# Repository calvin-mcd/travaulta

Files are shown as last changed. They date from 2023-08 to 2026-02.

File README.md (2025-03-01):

# travaultas

The travaultas are a series of EC (topre) pcbs for mechvault's [Vault35](https://mechvault.net/products/vault-35-mini-keyboard) series designed by calvin0563. 

The series consists of the HHKB and WKL pcbs, both supporting a single bottomrow layout with the double 1.75u splitbars, and the Number/Macropad, supporting all layout options. 

Firmware source code and the OEM plate file are available in their respective folders. In order to fit the topre pcb into the case, small modifications to some housings are necessary. Please refer to the extensive build guide by cia\_moonchild in order to learn how to make the assembled pcb fit into the vault35 case.

[Build Guide!!!](https://imgur.com/a/L5vGjtF)

**BEWARE**: The HHKB pcb has been fully tested and confirmed to work. The WKL and Numpad have not yet been prototyped and still require firmware. 

## Layout

**HHKB**
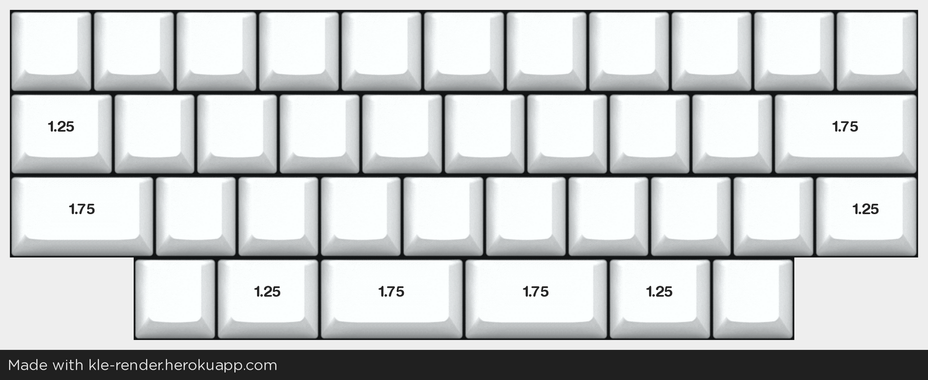
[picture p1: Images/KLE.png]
HHKB

[Link](http://www.keyboard-layout-editor.com/#/gists/d333b15956554a98cf3ed6f06e2de3bf)

**WKL**
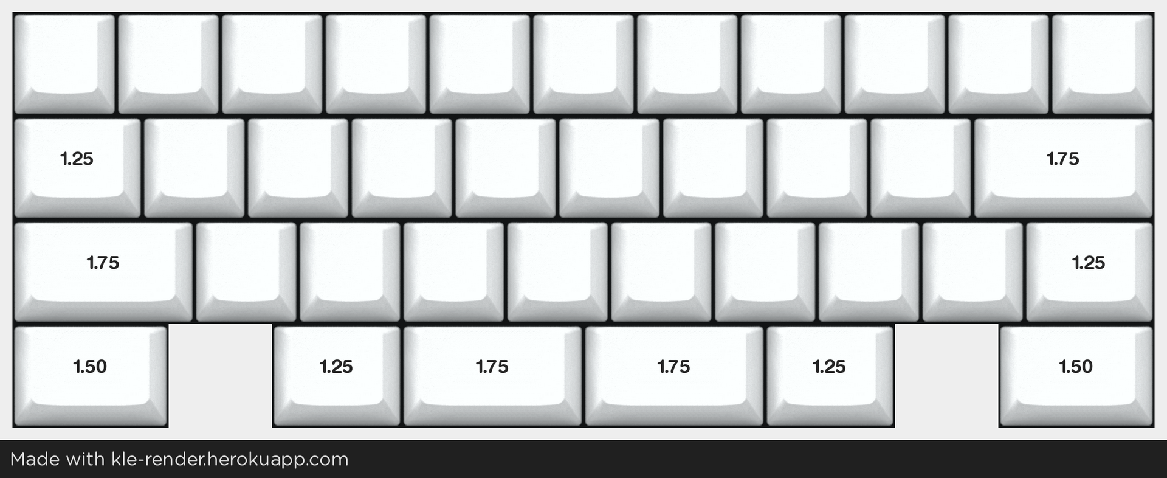
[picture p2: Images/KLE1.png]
WKL

[Link](https://www.keyboard-layout-editor.com/#/gists/da6e12de7bd5171aa8982730b8f45f17)

**NUMPAD**

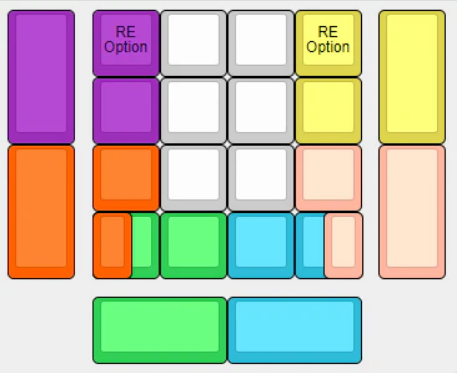
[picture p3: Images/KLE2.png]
Numpad


## Images
  
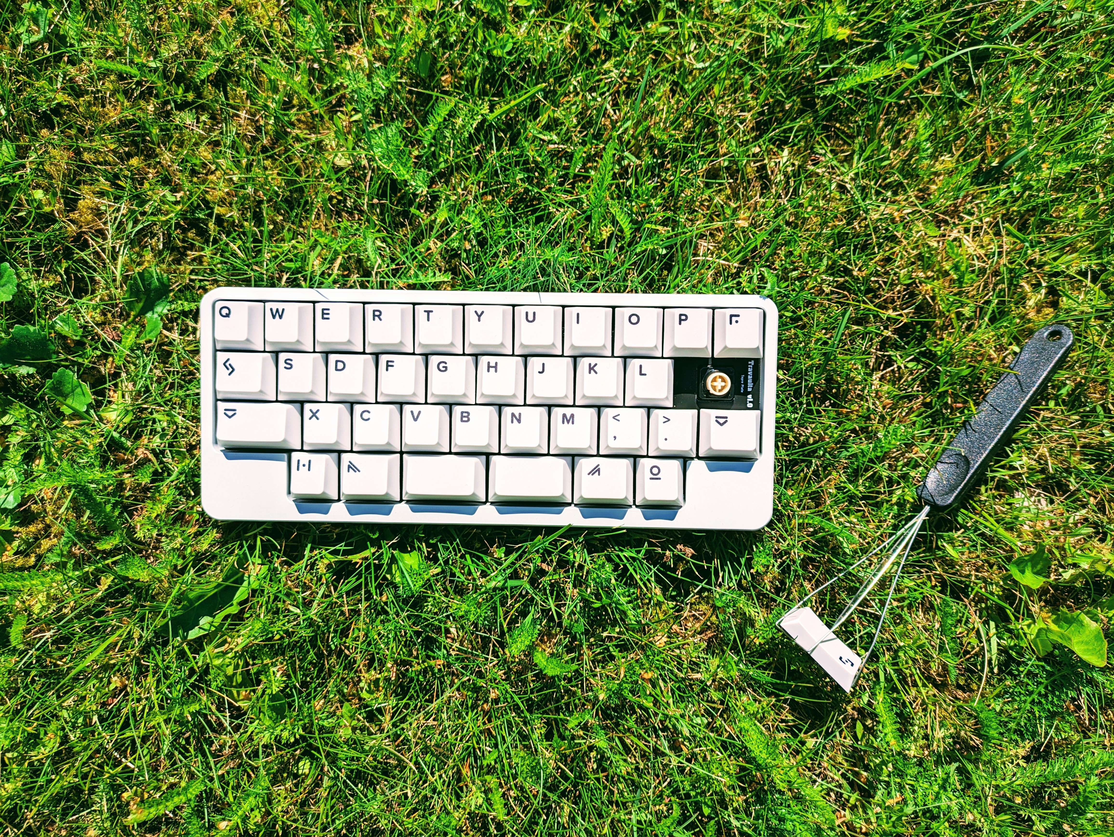
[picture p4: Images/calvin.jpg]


## Firmware

The basic EC firmware is ready to go and the source code is provided for tweaking any settings.

## Plates & Hardware

The plate file is OEM housing (so original, deskey, klc, pbb housings should all work). Be sure to order the plate in 1.2mm thickness regardless of material.

Furthermore, you will need 17x 10mm M2 screws and M2 nuts to assemble the HHKB and WKL pcbs. And 6x 10mm M2 screws and nuts to assemble numbpad.

## Disclaimer

1) Please proceed with caution with respect to copyright issues when using this repository
2) Take note that this is strictly for non-commercial use only
3) This PCB has been fully tested and confirmed to work. The members of the PCB development team are however not liable if you end up with a non-functional pcb. Order at your own risk. Support will not be provided but pull requests will be reviewed and possibly accepted.

## License

Shield: 

This work is licensed under a  
[Creative Commons Attribution-NonCommercial-ShareAlike 4.0 International License](http://creativecommons.org/licenses/by-nc-sa/4.0/).



## Credits

big thanks go out to Cain both for the inspiration and the support! My topre work is heavily lifted of Cipulot\#8455's open source work. I could not have done it without these resources. So I want to thank both cipulot and matthewdias\#2671 for their direct input, feedback and help along the way. Much much appreciated!

So many other thanks to go around, I fear I will forget people. There is Ciantha with their amazing guide! A whole bunch of early supporters that made the proto order possible. The keyboard Atelier discord for support. ssbb\#9052 with help with the firmware! And finally Alas/Sofia who decided to get a first GB for this on its feet!!

Any questions, contact Calvin0563 on Discord.

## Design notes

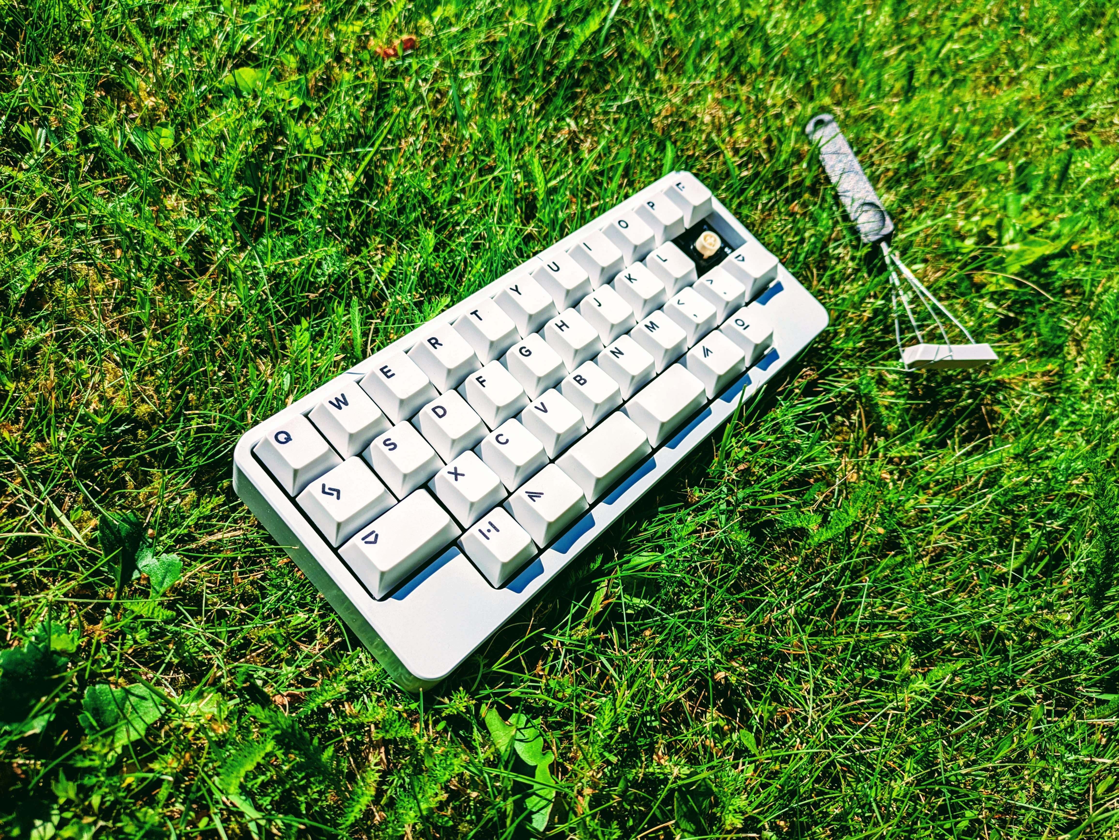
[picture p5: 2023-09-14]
Images/calvin (2).jpg

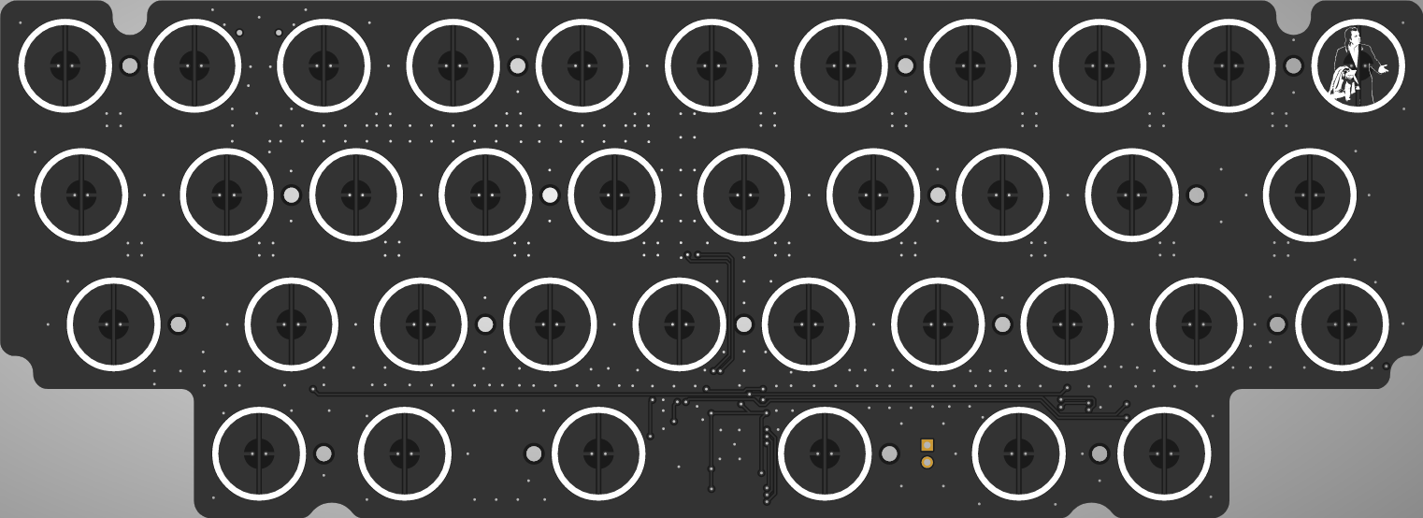
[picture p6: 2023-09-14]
Images/top.png

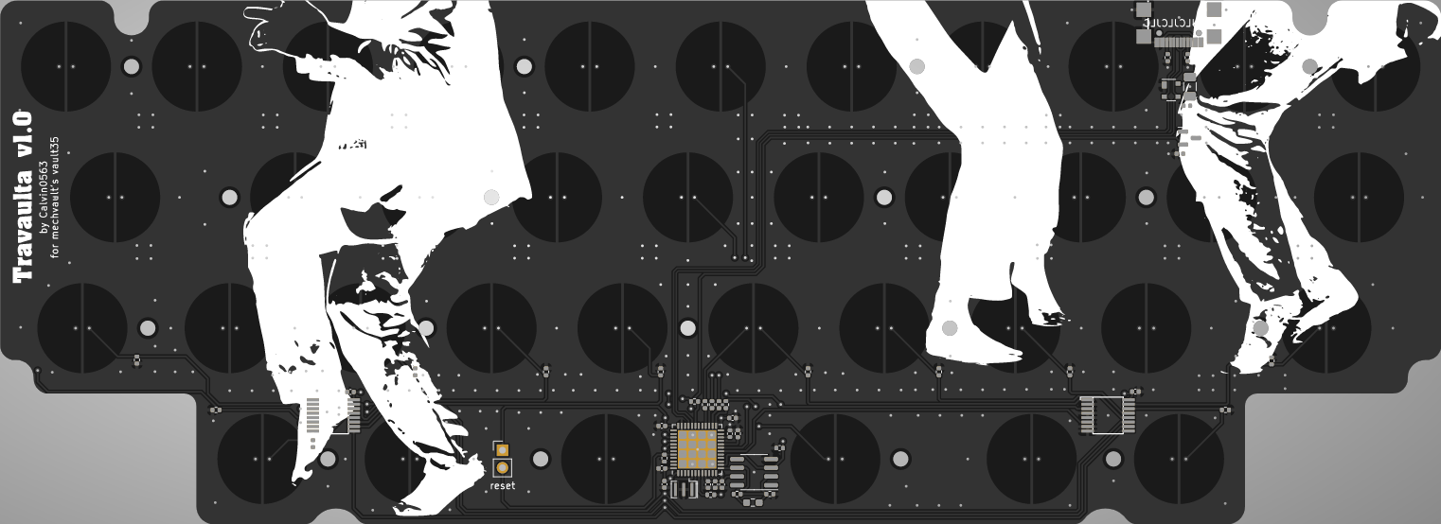
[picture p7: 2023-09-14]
Images/bottom.png

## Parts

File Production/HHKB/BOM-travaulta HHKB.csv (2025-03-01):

Comment | Designator | Footprint | LCSC | Quantity
1k | R23 | R_0402_1005Metric | C11702 | 1
STM32F401CBUx | U1 | QFN-48-1EP_7x7mm_P0.5mm_EP5.6x5.6mm | C118825 | 1
OPA350 | U5 | SOIC-8_3.9x4.9mm_P1.27mm | C13388 | 1
220p | C14 | C_0402_1005Metric | C1530 | 1
4.7u | C1 | C_0402_1005Metric | C23733 | 1
100 | R1,R2,R8,R9 | R_0402_1005Metric | C25076 | 4
100k | R10,R11,R12,R13,R14,R15,R16,R17,R19,R20,R21,R4,R5 | R_0402_1005Metric | C25741 | 13
10k | R3,R6,R7 | R_0402_1005Metric | C25744 | 3
5.1k | R18,R24 | R_0402_1005Metric | C25905 | 2
PRTR5V0U2X | D1 | SOT-143 | C2827688 | 1
TYPEC-304YSSW-ACP16 | USB1 | TYPEC-304YSSW-ACP16 | C2840392 | 1
100n | C10,C12,C13,C15,C6,C7,C8,C9 | C_0402_1005Metric | C307331 | 8
1u | C11,C4,C5 | C_0402_1005Metric | C52923 | 3
XC6206PxxxMR | U2 | SOT-23 | C5446 | 1
74HC4051 | U3,U4 | TSSOP16 | C5645 | 2
500mA | F_USBC1 | Fuse_1206_3216Metric | C70076 | 1
8 MHz | Y1 | Resonator_SMD_Murata_CSTxExxV-3Pin_3.0x1.1mm | C907975 | 1

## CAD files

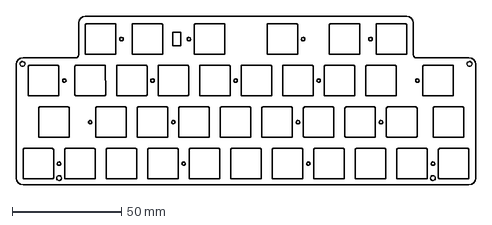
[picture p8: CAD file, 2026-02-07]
Production/HHKB/plate options/naevies.dxf
210.7 x 77.4 mm

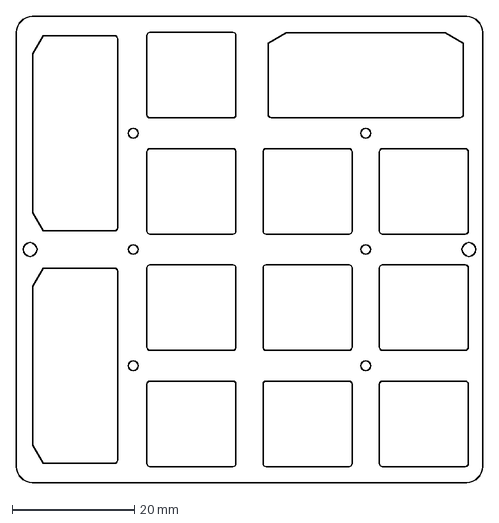
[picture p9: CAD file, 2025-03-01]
Production/Numpad/travaulta 16 2u.dxf
76.5 x 76.5 mm

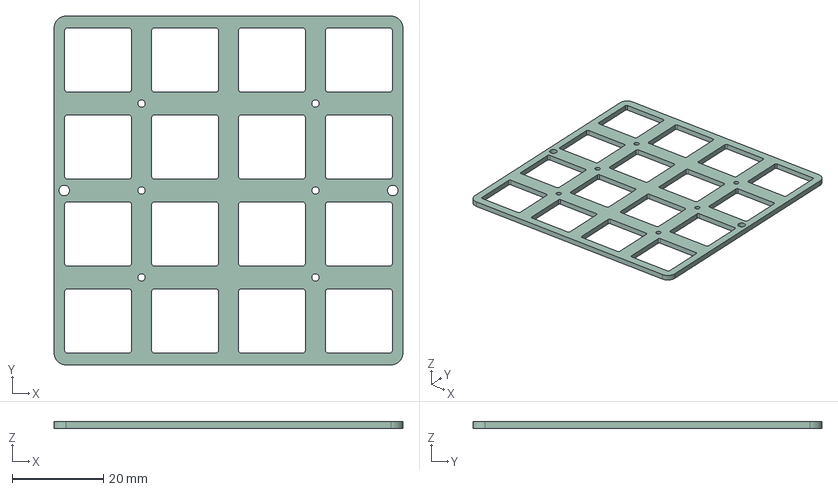
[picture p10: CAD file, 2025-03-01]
Project/travaulta 16/plate 1u threaded.step
76.5 x 76.4 x 1.60 mm

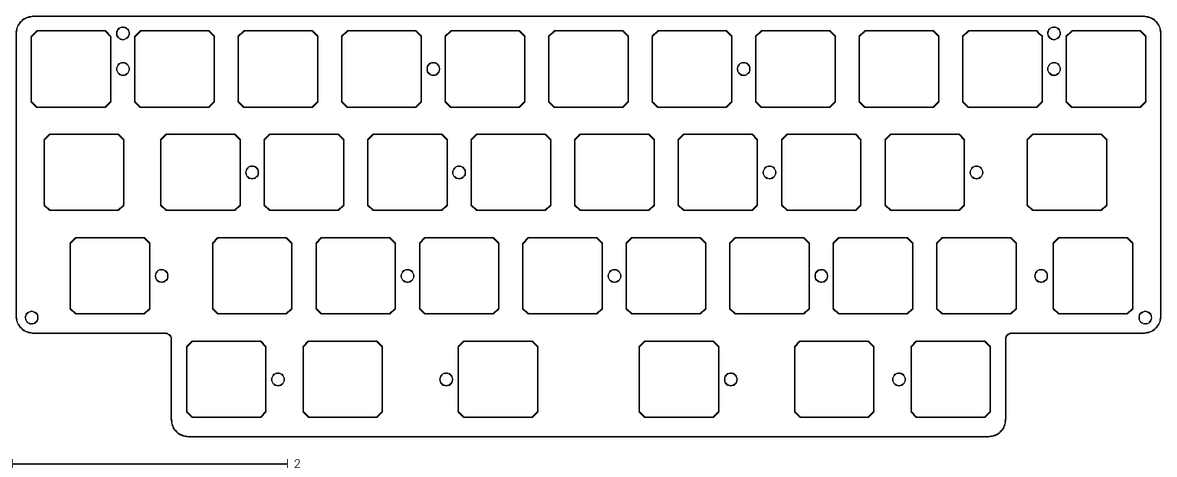
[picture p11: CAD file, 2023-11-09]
Project/travaulta HHKB/plates/production/plates/dxf/travaulta plate topre-B_Cu.dxf
8.30 x 3.05

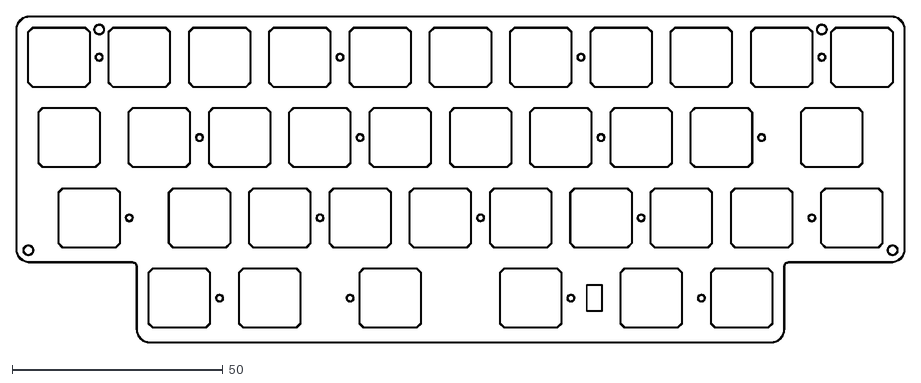
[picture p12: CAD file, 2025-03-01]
Project/travaulta HHKB/plates/production/plates/travaulta plate topre threaded-Edge_Cuts.dxf
210.9 x 77.5

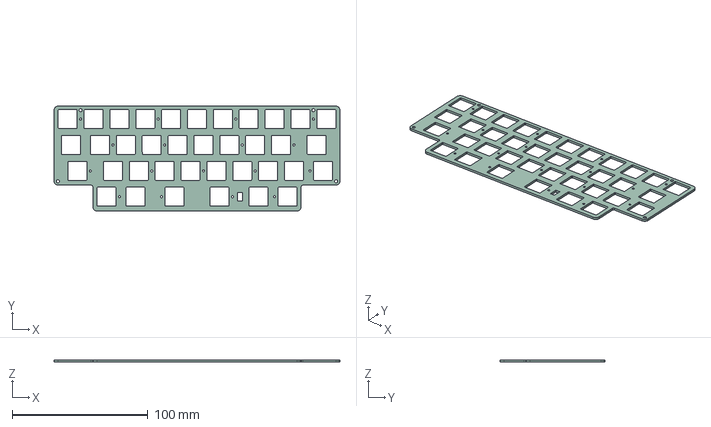
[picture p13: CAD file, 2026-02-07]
Project/travaulta HHKB/plates/travaulta plate naevies threaded.step
210.7 x 77.4 x 1.59 mm

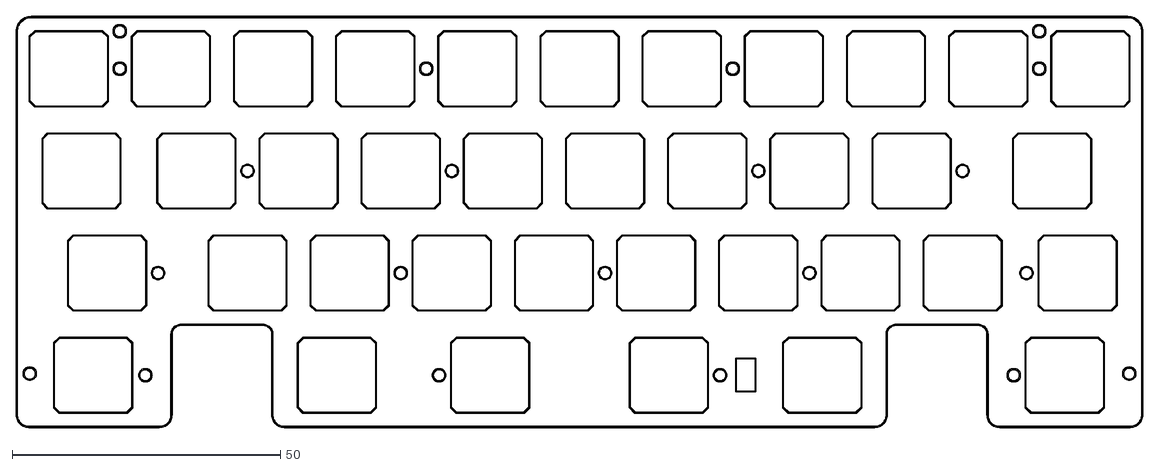
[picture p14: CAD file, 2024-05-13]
Project/travaulta WKL/Production/plate wkl-Edge_Cuts.dxf
210.0 x 76.7

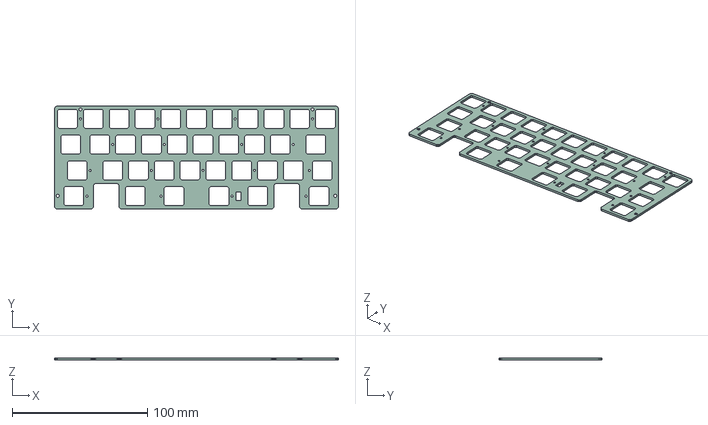
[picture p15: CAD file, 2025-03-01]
Project/travaulta WKL/travaulta WLK plate.step
209.8 x 76.5 x 1.57 mm

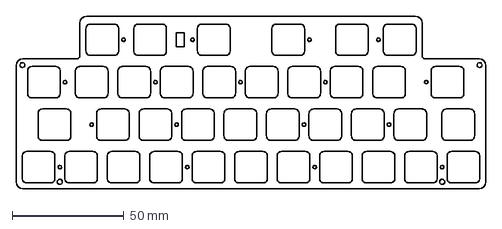
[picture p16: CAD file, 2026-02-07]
Production/HHKB/plate options/dyna.dxf
210.7 x 77.4 mm

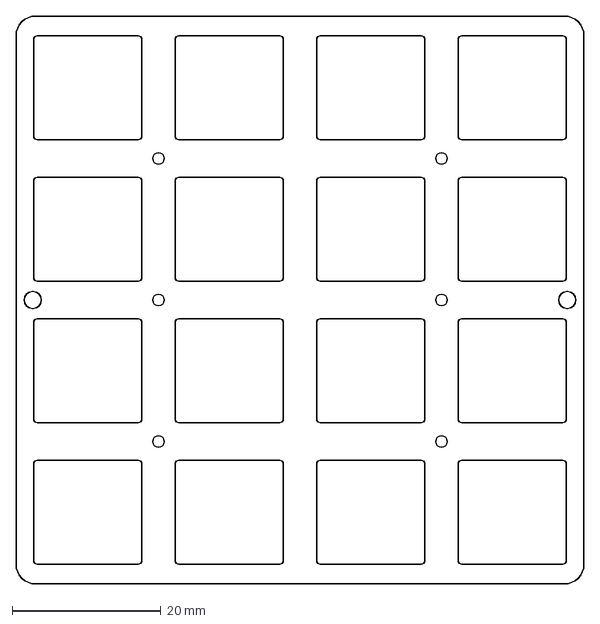
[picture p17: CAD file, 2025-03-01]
Production/Numpad/travaulta 16 1u.dxf
76.5 x 76.5 mm

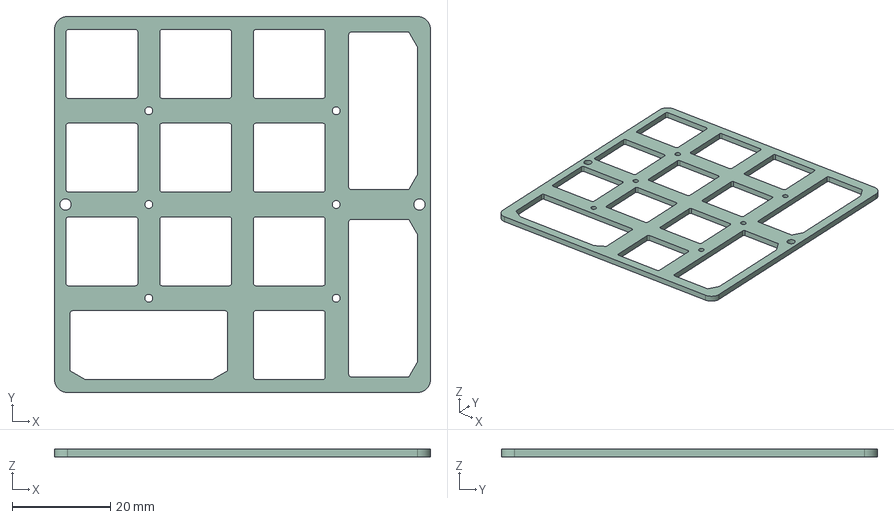
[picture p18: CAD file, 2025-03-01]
Project/travaulta 16/plate 2u threaded.step
76.4 x 76.5 x 1.60 mm

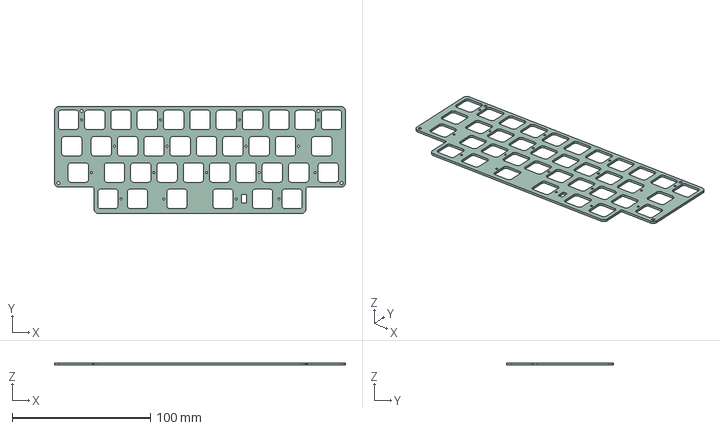
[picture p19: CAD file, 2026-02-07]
Project/travaulta HHKB/plates/travaulta plate dyna threaded.step
210.7 x 77.4 x 1.59 mm

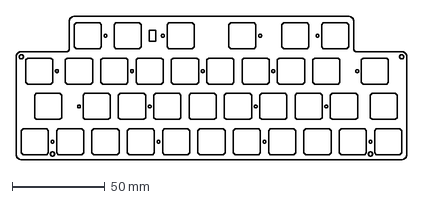
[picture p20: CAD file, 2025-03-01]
Production/HHKB/plate options/travaulta_hhkb_threaded.dxf
210.7 x 77.3 mm

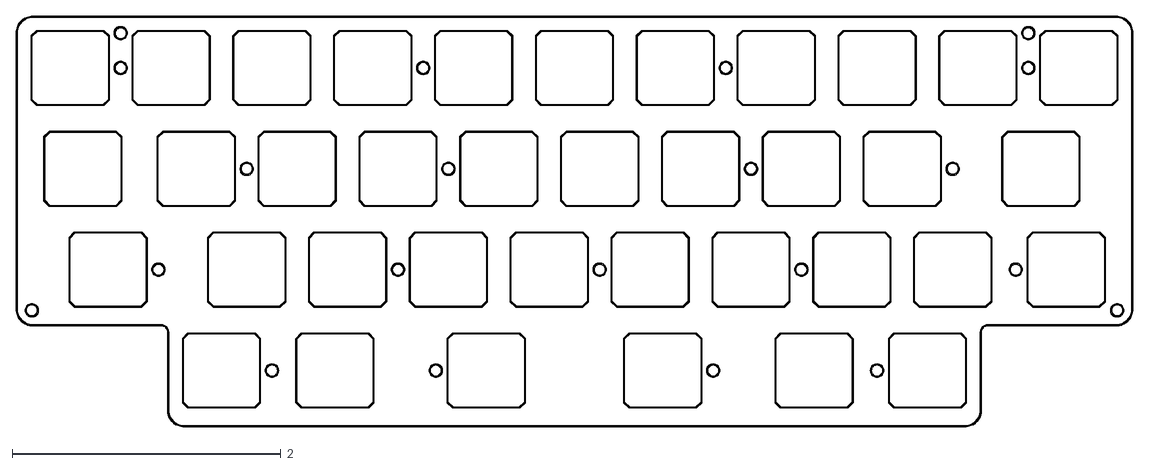
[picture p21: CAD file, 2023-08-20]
Project/travaulta HHKB/plates/production/plates/dxf/travaulta plate topre-Edge_Cuts.dxf
8.30 x 3.05

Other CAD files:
Project/travaulta HHKB/plates/production/plates/dxf/travaulta plate niz-B_Cu.dxf
Project/travaulta HHKB/plates/production/plates/dxf/travaulta plate niz-B_Mask.dxf
Project/travaulta HHKB/plates/production/plates/dxf/travaulta plate niz-B_Paste.dxf
Project/travaulta HHKB/plates/production/plates/dxf/travaulta plate niz-B_Silkscreen.dxf
Project/travaulta HHKB/plates/production/plates/dxf/travaulta plate niz-Edge_Cuts.dxf
Project/travaulta HHKB/plates/production/plates/dxf/travaulta plate niz-F_Cu.dxf
Project/travaulta HHKB/plates/production/plates/dxf/travaulta plate niz-F_Mask.dxf
Project/travaulta HHKB/plates/production/plates/dxf/travaulta plate niz-F_Paste.dxf
Project/travaulta HHKB/plates/production/plates/dxf/travaulta plate niz-F_Silkscreen.dxf
Project/travaulta HHKB/plates/production/plates/dxf/travaulta plate rgb-B_Cu.dxf
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

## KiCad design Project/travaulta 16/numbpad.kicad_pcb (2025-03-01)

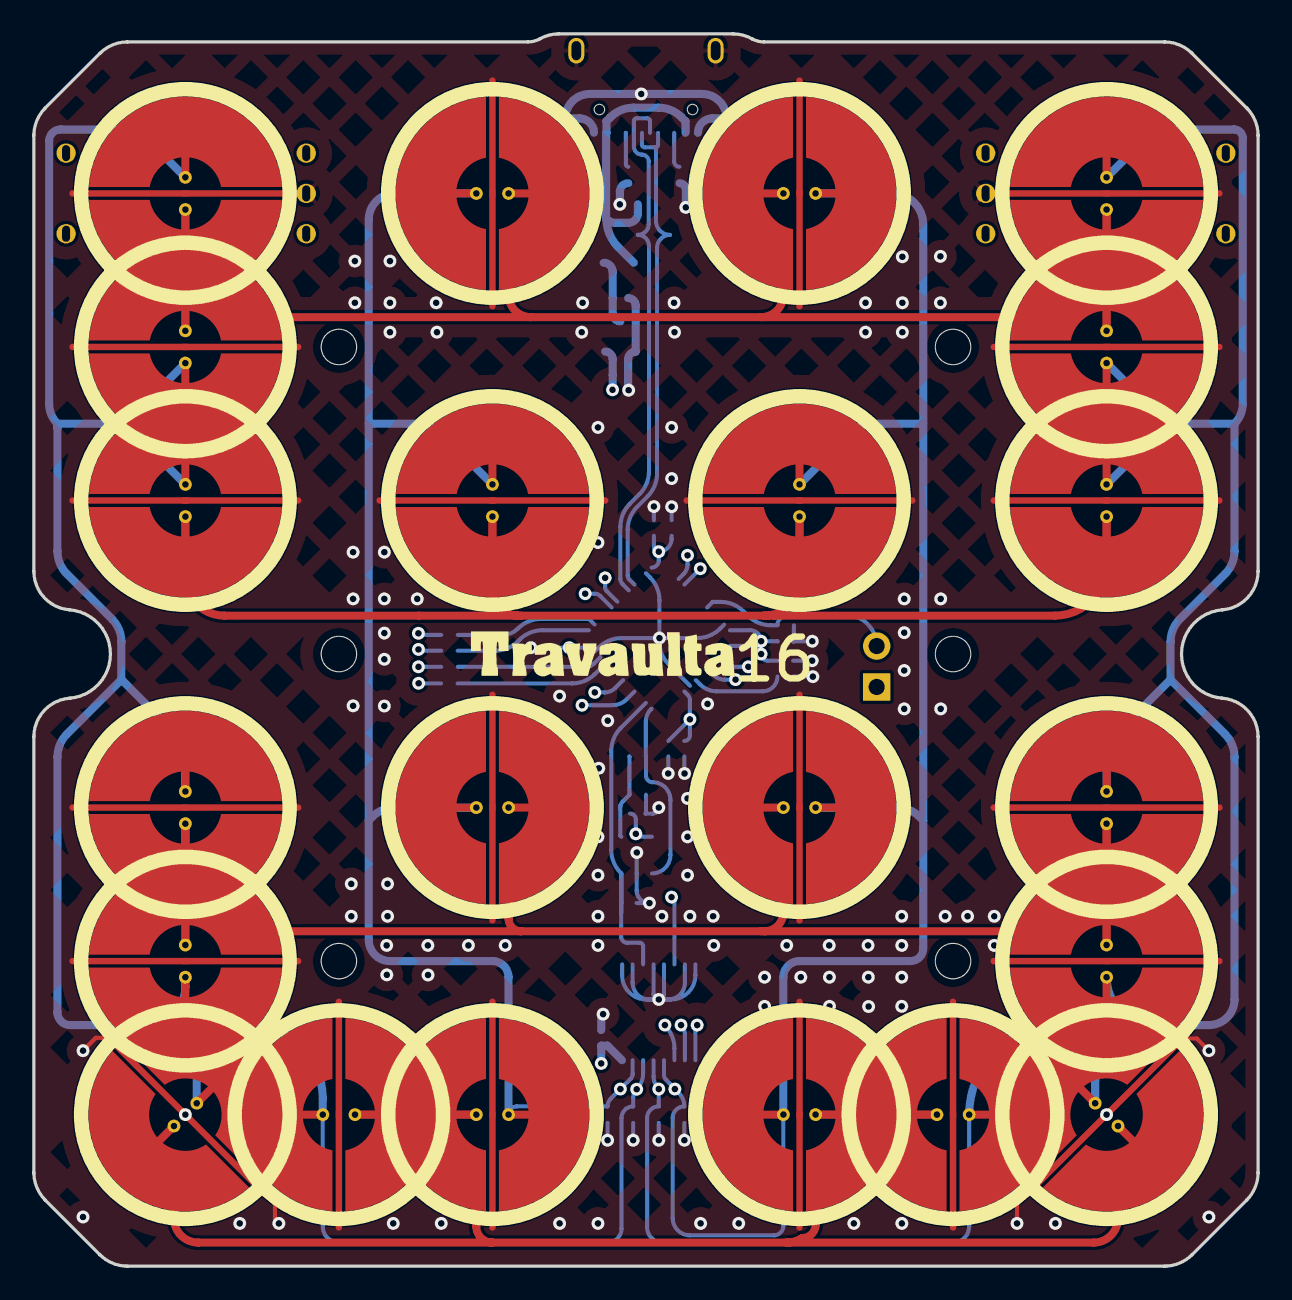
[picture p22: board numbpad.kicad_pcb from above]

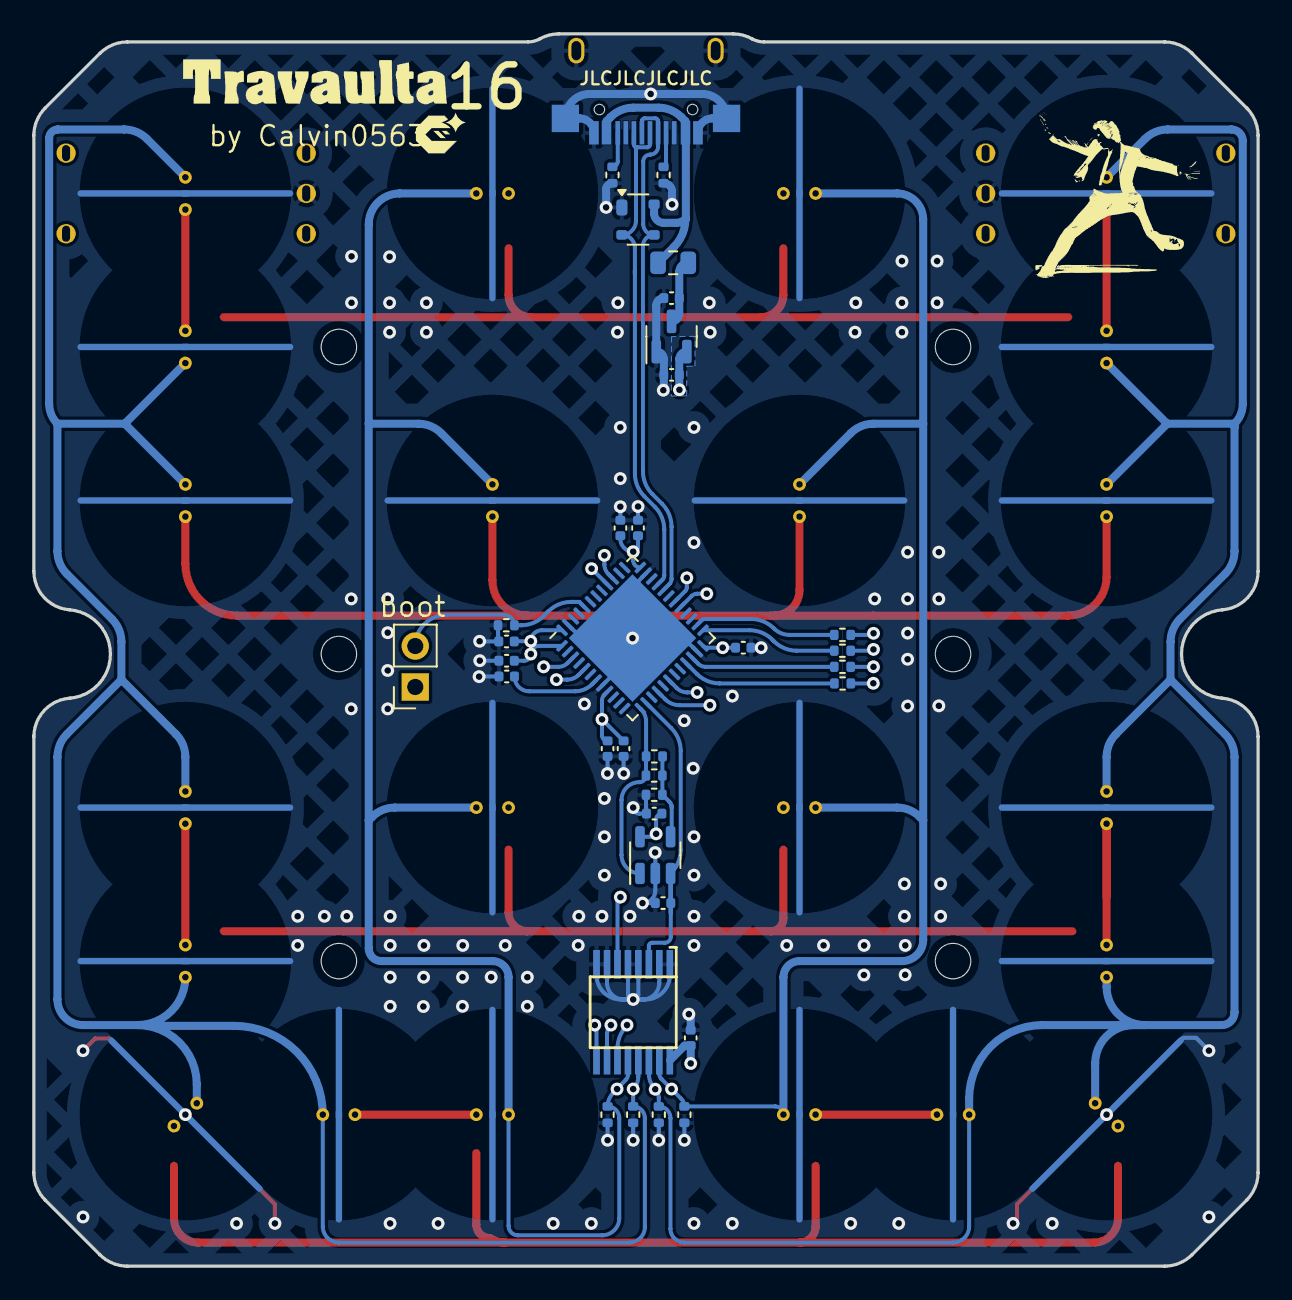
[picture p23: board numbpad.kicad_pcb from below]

Board: 4 copper layers, 76.0 x 76.5 mm, 63 parts (41 on the bottom side), 33 nets.

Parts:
C1, C2, C3, C4, C5, C7: 100nf; C_0402_1005Metric
C6: 10uF; C_0402_1005Metric
C8: 1uF; C_0402_1005Metric
C9, C10: 100nF; C_0402_1005Metric
C11: 220pF NP0; C_0402_1005Metric
C_LDO1, C_LDO2: 1uF; C_0402_1005Metric
F1: 500mA; Fuse_0805_2012Metric
H1, H2, H3, H4, H5, H6: MountingHole; HOLE_M2
R1: 10k; R_0402_1005Metric
R2, R3, R4, R5: 100; R_0402_1005Metric
R6, R7, R8, R9, R11: 100k; R_0402_1005Metric
R12: 1k; R_0402_1005Metric
R13: DNP; R_0402_1005Metric
R_USB1, R_USB2: 5.1k; R_0402_1005Metric
SW1, SW2, SW3, SW4, SW5, SW6, SW7, SW8, SW9, SW10, SW11, SW12, SW13, SW14, SW15, SW16, SW18, SW19, SW21, SW22: EC_SW; ecs_pad_1U_no_ring
SW17: SKQGABE010; PinSocket_1x02_P2.54mm_Vertical
SW20, SW23: EC_SW_RotaryEncoder_Switch; ecs_pad_1U_no_ring_rotary_encoder_ec12
U1: STM32F072CBUx; QFN-48-1EP_7x7mm_P0.5mm_EP5.6x5.6mm
U2: PRTR5V0U2X; SOT-143
U3: XC6206PxxxMR; SOT-23
U4: 74HC4051; TSSOP16
U5: OPA354; SOT-23-5
USB1: HRO-TYPE-C-31-M-12; XUNPU-TYPEC-312DSS-ACP16-Assembly

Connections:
+3V3: C2.1, C3.1, C4.1, C5.1, C6.1, C7.1, C8.1, C9.2, C10.2, C_LDO2.1, SW17.1, U1.1 (VBAT), U1.9 (VDDA), U1.24 (VDD), U1.36 (VDDIO2), U1.48 (VDD), U3.2 (VO), U4.16 (VCC), U5.5 (V+)
+5V: C_LDO1.1, F1.2, U3.3 (VI)
ADC: R11.1, R13.1, U1.13 (PA3), U5.1
AMUX_SEL_0: U1.16 (PA6), U4.11 (S0)
AMUX_SEL_1: U1.18 (PB0), U4.10 (S1)
AMUX_SEL_2: U1.3 (PC14), U4.9 (S2)
APLEX_EN_PIN_0: U1.5 (PF0), U4.6 (~E)
APLEX_OUT: C11.1, U1.14 (PA4), U4.3 (A), U5.3 (+)
BOOT0: R1.1, SW17.2, U1.44 (BOOT0)
Col 0: R8.1, SW1.1, SW5.1, SW9.1, SW13.1, SW18.1, SW20.2, SW22.1, U4.14 (A1)
Col 1: R6.1, SW2.1, SW6.1, SW10.1, SW14.1, U4.15 (A2)
Col 2: R9.1, SW3.1, SW7.1, SW11.1, SW15.1, U4.12 (A3)
Col 3: R7.1, SW4.1, SW8.1, SW12.1, SW16.1, SW19.1, SW21.1, SW23.1, U4.13 (A0)
D+: U1.33 (PA12), U2.2 (I/O1), USB1.6 (DP1), USB1.8 (DP2)
D-: U1.32 (PA11), U2.3 (I/O2), USB1.5 (DN2), USB1.7 (DN1)
GND: C1.2, C2.2, C3.2, C4.2, C5.2, C6.2, C7.2, C8.2, C9.1, C10.1, C11.2, C_LDO1.2, C_LDO2.2, R1.2, R6.2, R7.2, R8.2, R9.2, R12.2, R_USB1.2, R_USB2.2, SW1.3 (SG), SW2.3 (SG), SW3.3 (SG), SW4.3 (SG), SW5.3 (SG), SW6.3 (SG), SW7.3 (SG), SW8.3 (SG), SW9.3 (SG), SW10.3 (SG), SW11.3 (SG), SW12.3 (SG), SW13.3 (SG), SW14.3 (SG), SW15.3 (SG), SW16.3 (SG), SW18.3 (SG), SW19.3 (SG), SW20.3, SW20.C, SW21.3 (SG), SW22.3 (SG), SW23.3, SW23.C, U1.8 (VSSA), U1.23 (VSS), U1.35 (VSS), U1.47 (VSS), U1.49 (VSS), U2.1 (GND), U3.1 (GND), U4.1 (A4), U4.2 (A6), U4.4 (A7), U4.5 (A5), U4.7 (VEE), U4.8 (GND), U5.2 (V-), USB1.1 (GND), USB1.12 (GND), USB1.13 (SHIELD)
NRST: C1.1, U1.7 (NRST)
unnamed: R3.1, U1.21 (PB10)
unnamed: R2.1, U1.22 (PB11)
unnamed: R4.1, U1.25 (PB12)
unnamed: R5.1, U1.26 (PB13)
unnamed: R11.2, R12.1, R13.2, U5.4 (-)
unnamed: R_USB1.1, USB1.4 (CC1)
unnamed: R_USB2.1, USB1.10 (CC2)
Row 0: R4.2, SW2.2, SW3.2, SW18.2, SW19.2, SW20.1, SW23.2
Row 1: R5.2, SW5.2, SW6.2, SW7.2, SW8.2
Row 2: R2.2, SW1.2, SW9.2, SW10.2, SW11.2, SW12.2, SW21.2
Row 3: R3.2, SW4.2, SW13.2, SW14.2, SW15.2, SW16.2, SW22.2
VCC: F1.1, U2.4 (VCC), USB1.2 (VBUS), USB1.11 (VBUS)
rotA: SW20.A, U1.30 (PA9)
rotB: SW20.B, U1.29 (PA8)
rotC: SW23.A, U1.39 (PB3)
rotD: SW23.B, U1.40 (PB4)

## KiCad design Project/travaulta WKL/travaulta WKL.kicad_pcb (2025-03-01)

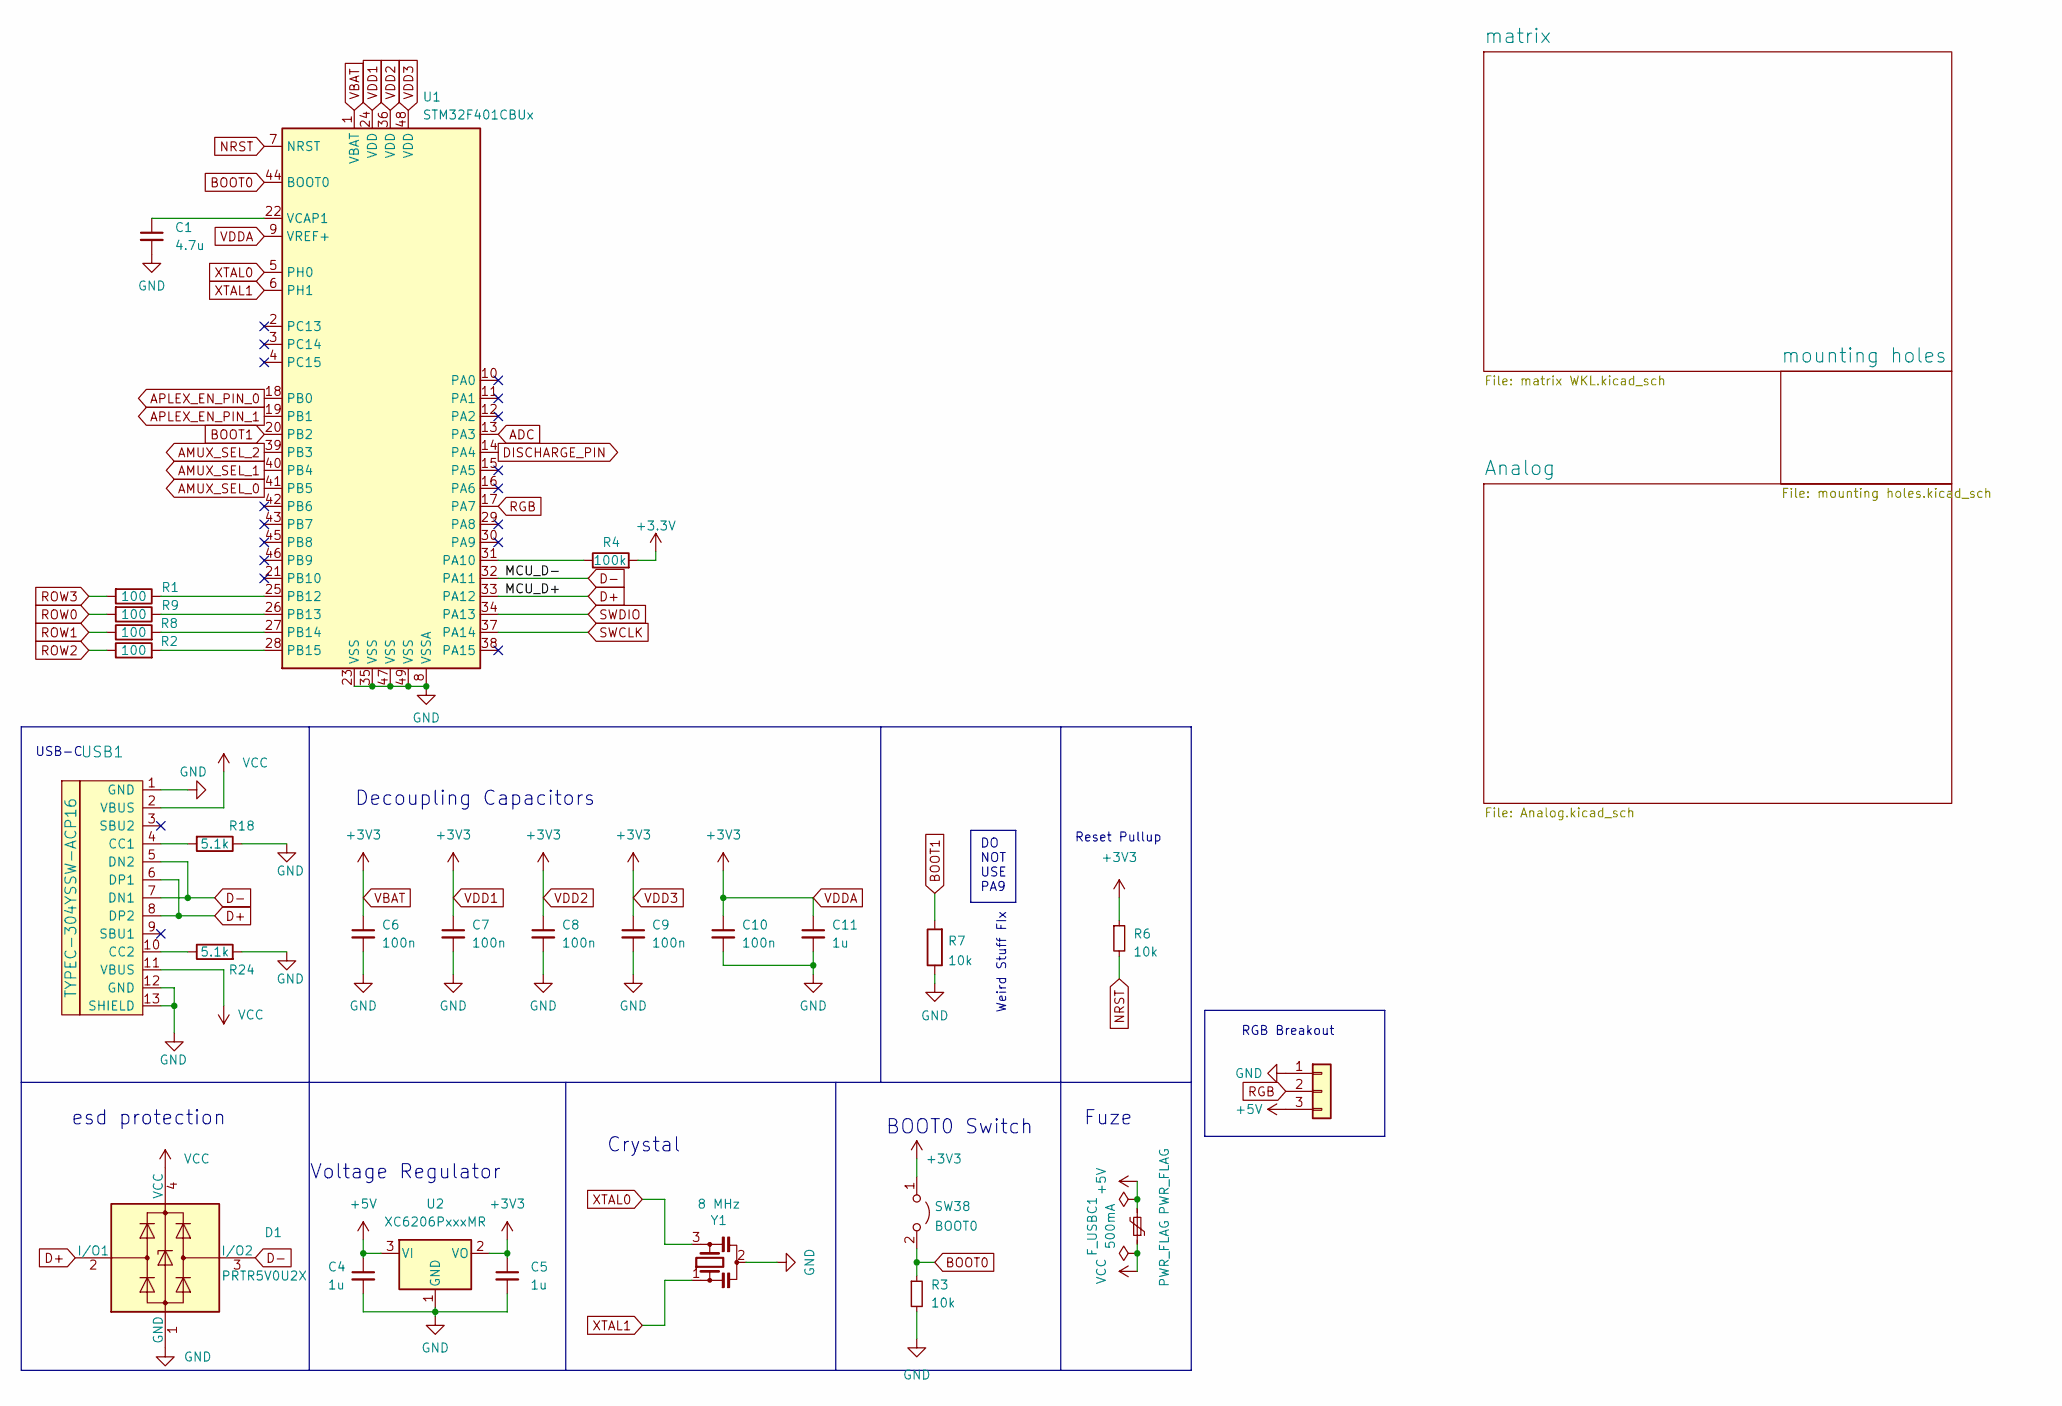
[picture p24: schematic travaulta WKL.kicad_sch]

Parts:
C1: 4.7u; C_0402_1005Metric
C4, C5, C11: 1u; C_0402_1005Metric
C6, C7, C8, C9, C10: 100n; C_0402_1005Metric
D1: PRTR5V0U2X; SOT-143
F_USBC1: 500mA; Fuse_1206_3216Metric
J5: ARGB; PinHeader_RGB strip
R1, R2, R8, R9: 100; R_0402_1005Metric; LCSC C25076
R3, R6: 10k; R_0402_1005Metric
R4: 100k; R_0402_1005Metric; LCSC C25741
R7: 10k; R_0402_1005Metric; LCSC C25744
R18, R24: 5.1k; R_0402_1005Metric; LCSC C25905
SW38: BOOT0; PinHeader_1x02_P2.54mm_Vertical
U1: STM32F401CBUx; QFN-48-1EP_7x7mm_P0.5mm_EP5.6x5.6mm; LCSC C118825
U2: XC6206PxxxMR; SOT-23
USB1: TYPEC-304YSSW-ACP16; XUNPU-TYPEC-312DSS-ACP16-Assembly; LCSC C2840392
Y1: 8 MHz; Resonator_SMD_Murata_CSTxExxV-3Pin_3.0x1.1mm; LCSC C907975

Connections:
+5V: C4.1, F_USBC1.2, U2.3 (VI); also elsewhere on the board
ADC: U1.13 (PA3); also elsewhere on the board
AMUX_SEL_0: U1.41 (PB5); also elsewhere on the board
AMUX_SEL_1: U1.40 (PB4); also elsewhere on the board
AMUX_SEL_2: U1.39 (PB3); also elsewhere on the board
APLEX_EN_PIN_0: U1.18 (PB0); also elsewhere on the board
APLEX_EN_PIN_1: U1.19 (PB1); also elsewhere on the board
APLEX_OUT_PIN_0: U1.14 (PA4); also elsewhere on the board
BOOT0: R3.1, SW38.2 (B), U1.44 (BOOT0)
BOOT1: R7.2, U1.20 (PB2)
D+: D1.2 (I/O1), U1.33 (PA12), USB1.6 (DP1), USB1.8 (DP2)
D-: D1.3 (I/O2), U1.32 (PA11), USB1.5 (DN2), USB1.7 (DN1)
NRST: R6.2, U1.7 (NRST)
unnamed: R4.1, U1.31 (PA10)
unnamed: R9.1, U1.26 (PB13)
unnamed: R8.2, U1.27 (PB14)
unnamed: R2.2, U1.28 (PB15)
unnamed: C1.1, U1.22 (VCAP1)
unnamed: R18.2, USB1.4 (CC1)
unnamed: R24.1, USB1.10 (CC2)
RGB: U1.17 (PA7); also elsewhere on the board
ROW0: R9.2; also elsewhere on the board
ROW1: R8.1; also elsewhere on the board
ROW2: R2.1; also elsewhere on the board
SWCLK: U1.37 (PA14)
SWDIO: U1.34 (PA13)
VCC: D1.4 (VCC), F_USBC1.1, USB1.2 (VBUS), USB1.11 (VBUS)
XTAL0: U1.5 (PH0), Y1.3
XTAL1: U1.6 (PH1), Y1.1

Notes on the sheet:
Weird Stuff FIx
BOOT0 Switch
USB-C
RGB Breakout
Voltage Regulator
Reset Pullup
esd protection
DO NOT USE PA9
Fuze
Crystal
Decoupling Capacitors

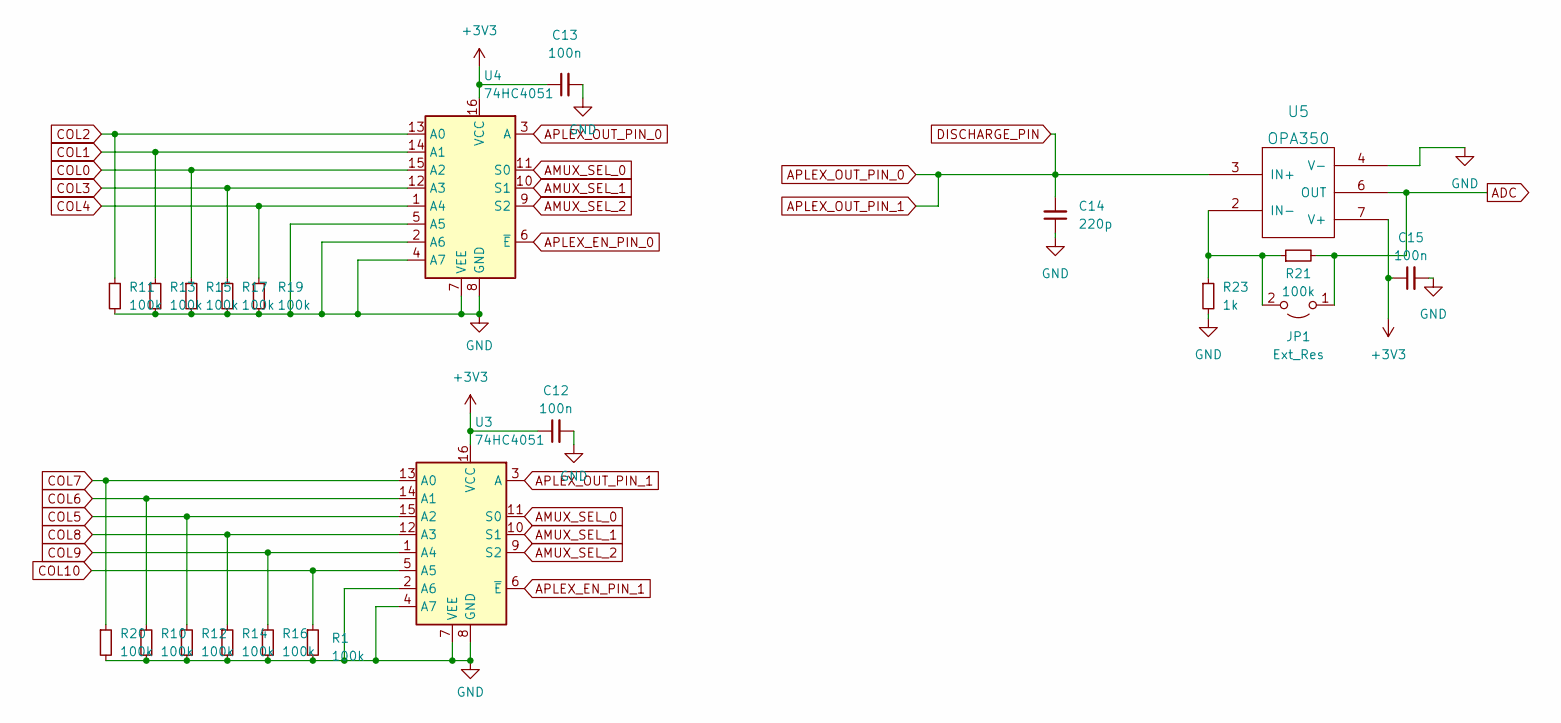
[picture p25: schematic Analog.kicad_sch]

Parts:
C12, C13, C15: 100n; C_0402_1005Metric
C14: 220p; C_0402_1005Metric
JP1: Ext_Res; R_0603_1608Metric_Pad0.98x0.95mm_HandSolder
R1, R10, R11, R12, R13, R14, R15, R16, R17, R19, R20, R21: 100k; R_0402_1005Metric
R23: 1k; R_0402_1005Metric
U3, U4: 74HC4051; TSSOP16
U5: OPA350; SOIC-8_3.9x4.9mm_P1.27mm

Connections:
ADC: JP1.1 (A), R21.2, U5.6 (OUT); also elsewhere on the board
AMUX_SEL_0: U3.11 (S0), U4.11 (S0); also elsewhere on the board
AMUX_SEL_1: U3.10 (S1), U4.10 (S1); also elsewhere on the board
AMUX_SEL_2: U3.9 (S2), U4.9 (S2); also elsewhere on the board
APLEX_EN_PIN_0: U4.6 (~E); also elsewhere on the board
APLEX_EN_PIN_1: U3.6 (~E); also elsewhere on the board
APLEX_OUT_PIN_0: C14.2, U3.3 (A), U4.3 (A), U5.3 (IN+); also elsewhere on the board
COL0: R15.1, U4.15 (A2); also elsewhere on the board
COL1: R13.1, U4.14 (A1); also elsewhere on the board
COL2: R11.1, U4.13 (A0); also elsewhere on the board
COL3: R17.1, U4.12 (A3); also elsewhere on the board
COL4: R19.1, U4.1 (A4); also elsewhere on the board
COL5: R12.1, U3.15 (A2); also elsewhere on the board
COL6: R10.1, U3.14 (A1); also elsewhere on the board
COL7: R20.1, U3.13 (A0); also elsewhere on the board
COL8: R14.1, U3.12 (A3); also elsewhere on the board
COL9: R16.1, U3.1 (A4); also elsewhere on the board
unnamed: JP1.2 (B), R21.1, R23.1, U5.2 (IN-)

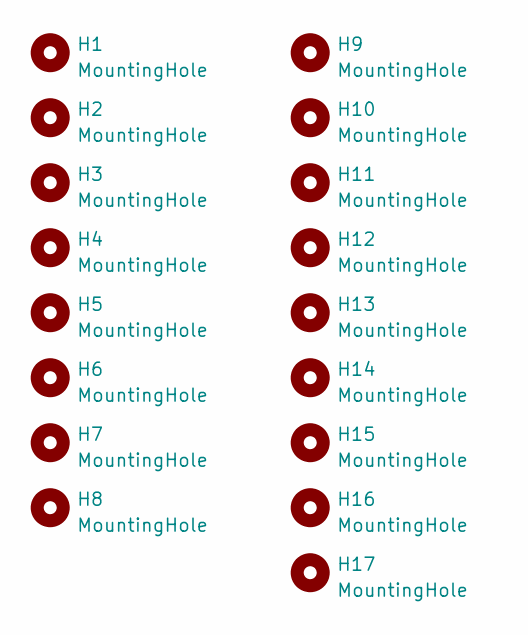
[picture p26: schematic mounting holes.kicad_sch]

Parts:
H1, H2, H3, H4, H5, H6, H7, H8, H9, H10, H11, H12, H13, H14, H15, H16, H17: MountingHole; HOLE_M2

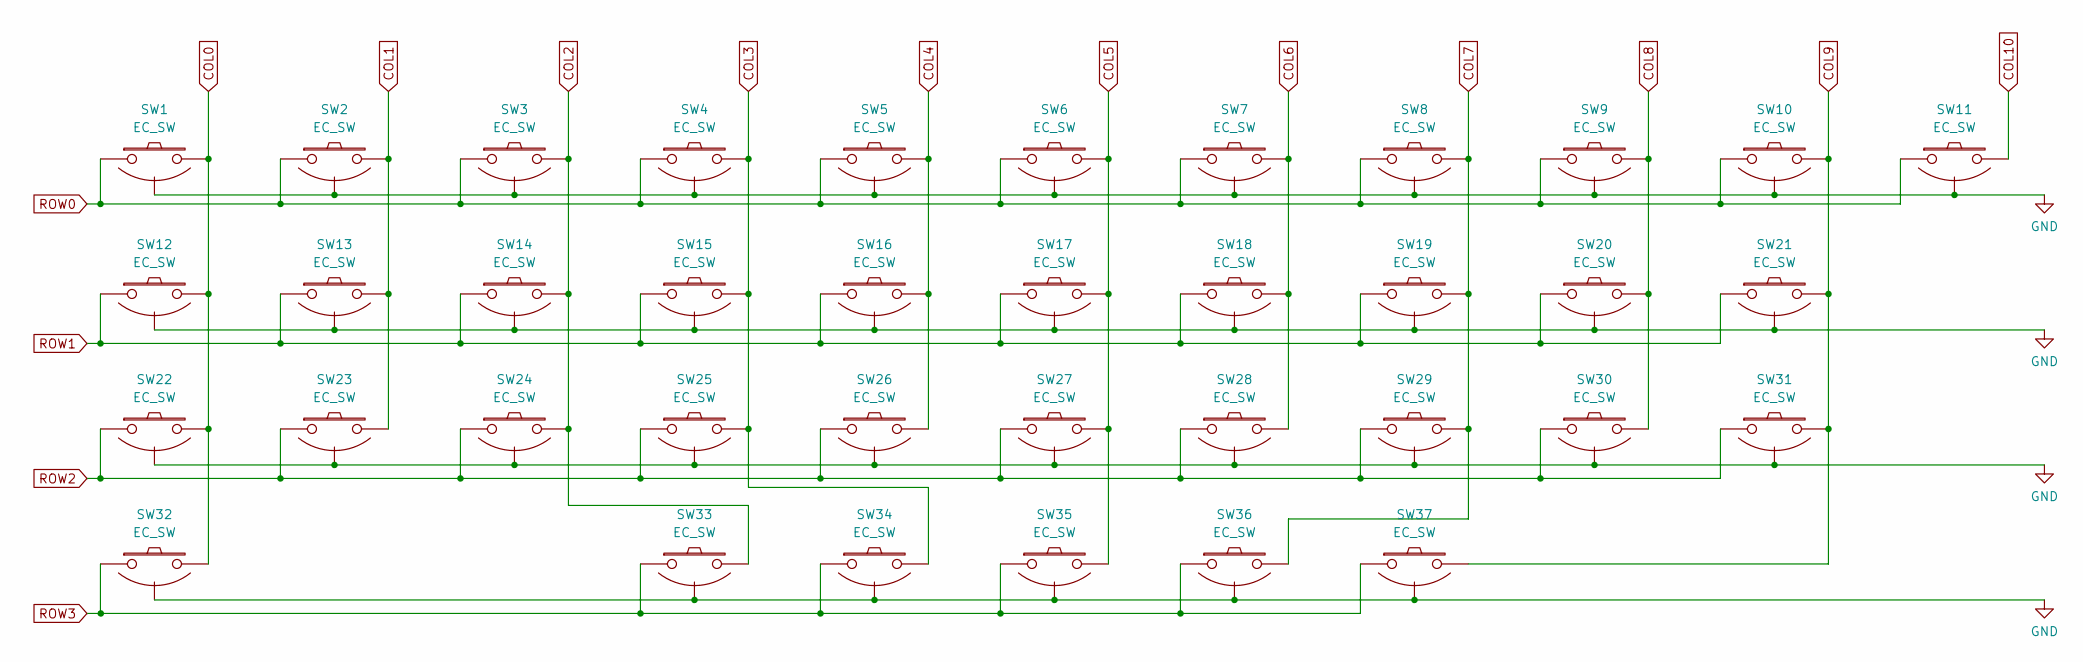
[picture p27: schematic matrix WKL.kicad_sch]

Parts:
SW1, SW2, SW3, SW4, SW5, SW6, SW7, SW8, SW9, SW10, SW11, SW12, SW13, SW14, SW15, SW16, SW17, SW18, SW19, SW20, SW21, SW22, SW23, SW24, SW25, SW26, SW27, SW28, SW29, SW30, SW31, SW32, SW33, SW34, SW35, SW36, SW37: EC_SW; ecs_pad_1U_no_ring

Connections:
COL0: SW1.2, SW12.2, SW22.2, SW32.2; also elsewhere on the board
COL1: SW2.2, SW13.2, SW23.2; also elsewhere on the board
COL2: SW3.2, SW14.2, SW24.2, SW33.2; also elsewhere on the board
COL3: SW4.2, SW15.2, SW25.2, SW34.2; also elsewhere on the board
COL4: SW5.2, SW16.2, SW26.2; also elsewhere on the board
COL5: SW6.2, SW17.2, SW27.2, SW35.2; also elsewhere on the board
COL6: SW7.2, SW18.2, SW28.2; also elsewhere on the board
COL7: SW8.2, SW19.2, SW29.2, SW36.2; also elsewhere on the board
COL8: SW9.2, SW20.2, SW30.2; also elsewhere on the board
COL9: SW10.2, SW21.2, SW31.2, SW37.2; also elsewhere on the board
ROW0: SW1.1, SW2.1, SW3.1, SW4.1, SW5.1, SW6.1, SW7.1, SW8.1, SW9.1, SW10.1, SW11.1; also elsewhere on the board
ROW1: SW12.1, SW13.1, SW14.1, SW15.1, SW16.1, SW17.1, SW18.1, SW19.1, SW20.1, SW21.1; also elsewhere on the board
ROW2: SW22.1, SW23.1, SW24.1, SW25.1, SW26.1, SW27.1, SW28.1, SW29.1, SW30.1, SW31.1; also elsewhere on the board

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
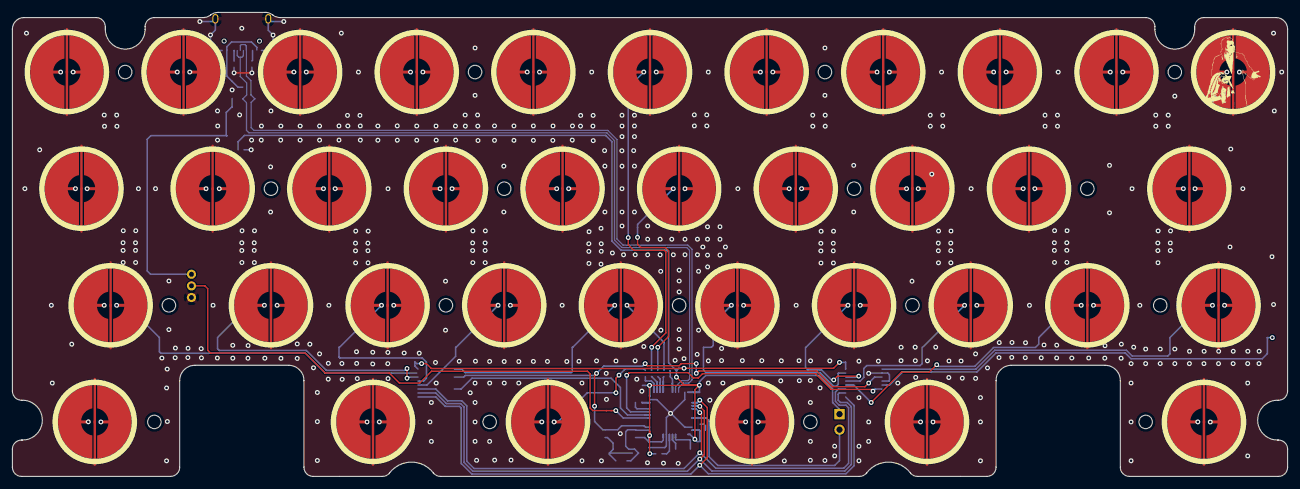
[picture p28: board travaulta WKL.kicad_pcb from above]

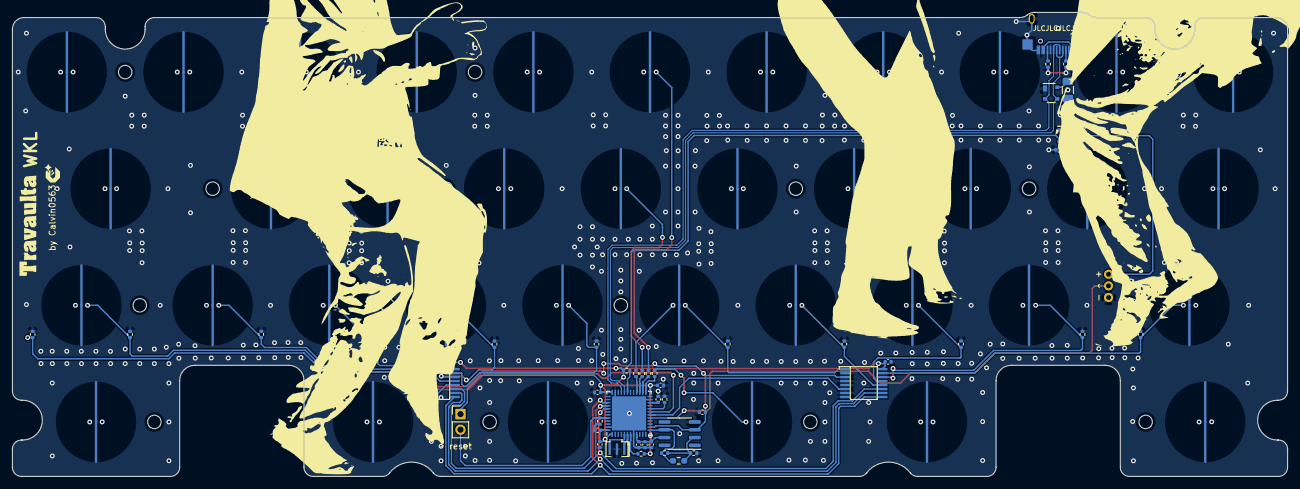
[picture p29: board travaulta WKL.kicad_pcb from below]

Board: 4 copper layers, 208.3 x 75.8 mm, 102 parts (47 on the bottom side), 43 nets.

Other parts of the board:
J1: ARGB; PinHeader_RGB strip
R5: 100k; R_0402_1005Metric

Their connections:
+5V: J1.3; also elsewhere on the board
RGB: J1.2; also elsewhere on the board

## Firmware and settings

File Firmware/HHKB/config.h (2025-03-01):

/* Copyright 2023 sporkus
 *
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
 * You should have received a copy of the GNU General Public License
 * along with this program.  If not, see <http://www.gnu.org/licenses/>.
 */

#pragma once

// --- EC matrix user configuration ---
// Actuation/release threshold = idle + offset
// Larger offset = More key travel distance, less sensitive
// Sensitivity can be adjusted using keycode: EC_AP_I/EC_AP_D
#define ACTUATION_OFFSET 150
#define RELEASE_OFFSET 170
#define DEFAULT_IDLE 500      // default value before tuning is completed
#define ECSM_DEBUG         // enables printing ec config and ADC readings
#define EC_MATRIX            // allows ec code to be enabled with ifdef

/* key matrix size */
#define MATRIX_ROWS 4
#define MATRIX_COLS 11

/* Custom matrix pins and port select array */
#define MATRIX_ROW_PINS \
    { B13, B14, B15, B12 }
#define MATRIX_COL_CHANNELS \
    { \
       2, 1, 0, 3, 4, \
       10, 9, 8, 11, 12, 13 \
    }

/* Hardware peripherals pins */
#define MUX_SEL_PINS \
    { B5, B4, B3 }

#define MUX_EN_PINS \
    { B0, B1 }

#define DISCHARGE_PIN A4
#define ANALOG_PORT A3

/* COL2ROW, ROW2COL */
#define DIODE_DIRECTION COL2ROW

/* Debounce reduces chatter (unintended double-presses) - set 0 if debouncing is not needed */
//#define DEBOUNCE 5

/* Mechanical locking support. Use KC_LCAP, KC_LNUM or KC_LSCR instead in keymap */
#define LOCKING_SUPPORT_ENABLE

/* Locking resynchronize hack */
#define LOCKING_RESYNC_ENABLE


// --- EC matrix user configuration ---
// Actuation/release threshold = idle + offset
// Larger offset = More key travel distance, less sensitive
// Sensitivity can be adjusted using keycode: EC_AP_I/EC_AP_D
#define ACTUATION_OFFSET 150
#define RELEASE_OFFSET 170
#define DEFAULT_IDLE 500      // default value before tuning is completed
#define ECSM_DEBUG         // enables printing ec config and ADC readings
#define EC_MATRIX            // allows ec code to be enabled with ifdef

// enables tuning ec config every power cycle, disable to reduce write cycle to flash
//#define ECSM_TUNE_ON_BOOT

// --- Persistent Storage config ---
// Data size is in bytes. uint16_t = 2 bytes
// data block size needs to be uint16_t array length * 2
// Two addition words for actuation offsets and one byte for configuration check
#define EECONFIG_KB_DATA_SIZE ((MATRIX_ROWS * MATRIX_COLS + 2) * 2 + 1)

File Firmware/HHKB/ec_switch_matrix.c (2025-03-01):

/* Copyright 2023 sporkus
 * Copyright 2023 Cipulot
 *
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
 * You should have received a copy of the GNU General Public License
 * along with this program.  If not, see <http://www.gnu.org/licenses/>.
 */

#include <math.h>
#include "ec_switch_matrix.h"
#include "analog.h"
#include "atomic_util.h"
#include "print.h"

/* Pin and port array */
const uint32_t row_pins[]     = MATRIX_ROW_PINS;
const uint8_t  col_channels[] = MATRIX_COL_CHANNELS;
const uint32_t mux_sel_pins[] = MUX_SEL_PINS;
const uint32_t mux_en_pins[] =  MUX_EN_PINS;

static adc_mux adcMux;
static uint16_t ecsm_sw_value[MATRIX_ROWS][MATRIX_COLS];

static ecsm_threshold_t ecsm_thresholds[MATRIX_ROWS][MATRIX_COLS];
static int16_t ecsm_tuning_data[MATRIX_ROWS][MATRIX_COLS];
static uint32_t ecsm_is_tuning = 1e5; // Tunes ec config until this counter reaches 0

/* fancy printing */
const char* red = "\x1b[31m";
const char* reset = "\x1b[0m";

static inline void discharge_capacitor(void) {
    writePinLow(DISCHARGE_PIN);
}

static inline void charge_capacitor(uint8_t row) {
    writePinHigh(DISCHARGE_PIN); // Blocks discharge route
    writePinHigh(row_pins[row]); // Send signal to row
}

static inline void disable_mux(uint8_t i) {
    writePinHigh(mux_en_pins[i]);
}

static inline void disable_mux_all(void) {
    for (int i = 0; i < 2; i++) {
        disable_mux(i);
    }
}

static inline void enable_mux(uint8_t i) {
    writePinLow(mux_en_pins[i]);
}

static inline void select_col(uint8_t col) {
    uint8_t ch = col_channels[col];
    uint8_t active_mux = (ch & 8) ? 1 : 0;

    disable_mux(!active_mux);
    writePin(mux_sel_pins[0], ch & 1);
    writePin(mux_sel_pins[1], ch & 2);
    writePin(mux_sel_pins[2], ch & 4);
    enable_mux(active_mux);
}

/// @brief hardware initialization for row pins
static inline void init_row(void) {
    for (int i = 0; i < MATRIX_ROWS; i++) {
        setPinOutput(row_pins[i]);
        writePinLow(row_pins[i]);
    }
}

/// @brief hardware initialization for mux
static inline void init_mux(void) {
    for (int i = 0; i < 2; i++) {
        setPinOutput(mux_en_pins[i]);
    }

    for (int idx = 0; idx < 3; idx++) {
        setPinOutput(mux_sel_pins[idx]);
    }
}

void ecsm_config_init(void) {
    eeconfig_read_kb_datablock(&ecsm_config);
    for (int i = 0; i < MATRIX_ROWS; i++) {
        for (int j = 0; j < MATRIX_COLS; j++) {
            if (! ecsm_config.configured) {
                // fallback to default values
                ecsm_config.actuation_offset = ACTUATION_OFFSET;
                ecsm_config.release_offset = RELEASE_OFFSET;
                ecsm_config.idle[i][j] = DEFAULT_IDLE;
            }
            ecsm_tuning_data[i][j] = ecsm_config.idle[i][j];
        }
    }
    ecsm_update_thresholds();
}

void ecsm_config_update(void) {
    for (int i = 0; i < MATRIX_ROWS; i++) {
        for (int j = 0; j < MATRIX_COLS; j++) {
            ecsm_config.idle[i][j] = ecsm_tuning_data[i][j];
        }
    }

    uprintf("Writing current actuation points to presistent storage\n");
    eeconfig_update_kb_datablock(&ecsm_config);
    ecsm_print_debug();
}

void ecsm_eeprom_clear(void) {
    uprintln("\nClearing EC config");
    ecsm_config.configured = 0;
    ecsm_config.actuation_offset = ACTUATION_OFFSET;
    ecsm_config.release_offset = RELEASE_OFFSET;
    for (int i = 0; i < MATRIX_ROWS; i++) {
        for (int j = 0; j < MATRIX_COLS; j++) {
            ecsm_config.idle[i][j] = 0;
        }
    }
    eeconfig_update_kb_datablock(&ecsm_config);
    ecsm_is_tuning = 1e5;
}

void ecsm_ap_inc(void) {
    int16_t max_offset = 400;
    uprintf("\nIncreasing actuation point (less sensitive)\n");
    ecsm_config.actuation_offset += 15;
    ecsm_config.release_offset += 15;

    if (ecsm_config.actuation_offset > max_offset || ecsm_config.release_offset > max_offset) {
        uprintf("\nActuation point at maximum\n");
        int offset_diff = RELEASE_OFFSET - ACTUATION_OFFSET;
        ecsm_config.actuation_offset = max_offset;
        ecsm_config.release_offset = max_offset + offset_diff;
    }

    ecsm_update_thresholds();
    ecsm_config_update();
}

void ecsm_ap_dec(void) {
    int16_t min_offset = 50;
    uprintf("\nDecreasing actuation point (more sensitive)\n");
    ecsm_config.actuation_offset -= 15;
    ecsm_config.release_offset -= 15;

    if (ecsm_config.actuation_offset < min_offset || ecsm_config.release_offset < min_offset) {
        uprintf("\nActuation point at minimum\n");
        int offset_diff = RELEASE_OFFSET - ACTUATION_OFFSET;
        ecsm_config.actuation_offset = min_offset;
        ecsm_config.release_offset = min_offset + offset_diff;
    }

    ecsm_update_thresholds();
    ecsm_config_update();
}


void ecsm_init(void) {
    palSetLineMode(ANALOG_PORT, PAL_MODE_INPUT_ANALOG);
    adcMux = pinToMux(ANALOG_PORT);
    //Dummy call to make sure that adcStart() has been called in the appropriate state
    adc_read(adcMux);

    // Initialize discharge pin as discharge mode
    writePinLow(DISCHARGE_PIN);
    setPinOutputOpenDrain(DISCHARGE_PIN);

    init_row();
    init_mux();
    ecsm_config_init();
}

void ecsm_update_tuning_data(int16_t new_value, uint8_t row, uint8_t col) {
    if (new_value < DEFAULT_IDLE + ACTUATION_OFFSET) {
        float curr = ecsm_tuning_data[row][col];
        float adjusted = curr + ((float)new_value - curr) * 0.02;
        ecsm_tuning_data[row][col] = round(adjusted);
    }
}

void ecsm_update_thresholds(void) {
    for (int i = 0; i < MATRIX_ROWS; i++) {
        for (int j = 0; j < MATRIX_COLS; j++) {
            int16_t idle = ecsm_tuning_data[i][j];
            ecsm_thresholds[i][j].actuation =  idle + ecsm_config.actuation_offset;
            ecsm_thresholds[i][j].release = idle + ecsm_config.release_offset;
        }
    }
}

uint16_t ecsm_readkey_raw(uint8_t row, uint8_t col) {
    uint16_t sw_value = 0;

    select_col(col);
    // Set strobe pins to idle state
    writePinLow(row_pins[row]);
    ATOMIC_BLOCK_FORCEON {
        charge_capacitor(row);
        __asm__ __volatile__("nop;nop;nop;\n\t");
        sw_value = adc_read(adcMux);
    }
    // reset sensor
    writePinLow(row_pins[row]);
    discharge_capacitor();
    return sw_value;
}

/// Comparing ADC reading to threshold to update press/release state of key
bool ecsm_update_key(matrix_row_t* current_row, uint8_t row, uint8_t col, uint16_t sw_value) {
    bool current_state = (*current_row >> col) & 1;

    // Press to release
    if (current_state && sw_value < ecsm_thresholds[row][col].release) {
        *current_row &= ~(1 << col);
        return true;
    }

    // Release to press
    if (!current_state && sw_value > ecsm_thresholds[row][col].actuation) {
        *current_row |= (1 << col);
        return true;
    }

    return false;
}
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

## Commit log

2023-01-29 switch footprints plaed
    [travaulta.kicad_pcb]
2023-01-30 analog schematics added
    some questions
    [Analog.kicad_sch, mounting holes.kicad_sch, travaulta.kicad_pcb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]
2023-02-02 question marker
    [travaulta.kicad_pcb]
2023-02-04 changed rol, col schematics /// made pcb 4 layers
    [matrix.kicad_sch, travaulta.kicad_pcb, travaulta.kicad_sch]
2023-02-06 early routing
    [matrix.kicad_sch, travaulta plate.kicad_pcb, travaulta.kicad_pcb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]
2023-02-12 component placement
    [Analog.kicad_sch, matrix.kicad_sch, mounting holes.kicad_sch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]
2023-02-13 component placement, some basic silkscreen prep
    [travaulta.kicad_pcb]
2023-02-14 routing work
    [Analog.kicad_sch, matrix.kicad_sch, travaulta.kicad_pcb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]
2023-02-14 created simplified version
    [Analog simplified.kicad_sch, matrix.kicad_sch, mounting holes.kicad_sch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]
2023-02-16 cleaned pcb, silkscreen, created first plates
    [travaulta plate niz.kicad_pcb, travaulta plate topre.kicad_pcb, travaulta plate.kicad_pcb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]
2023-02-17 created more plates
    [Analog simplified.kicad_sch, travaulta plate niz.kicad_pcb, travaulta plate rgb.kicad_pcb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]
2023-02-18 clean up folders, edit silkscreen
    [Analog simplified.kicad_sch, Analog.kicad_sch, matrix.kicad_sch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]
2023-02-19 silkscreen work
    [travaulta.kicad_pcb]
2023-02-20 plate cutouts
    needs plate edge cut
    [travaulta plate niz.kicad_pcb, travaulta plate rgb.kicad_pcb, travaulta plate topre.kicad_pcb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]
2023-02-21 first draft plates complete
    [travaulta plate niz.kicad_pcb, travaulta plate rgb.kicad_pcb, travaulta plate topre.kicad_pcb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]
2023-02-23 rgb attempt
    [Analog.kicad_sch, matrix.kicad_sch, mounting holes.kicad_sch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]
2023-02-23 first rough rgb version done
    no idea about interferences and all.
    [travaulta rgb.kicad_pcb, travaulta rgb.kicad_sch]
2023-03-02 production files
    [Analog.kicad_sch, matrix.kicad_sch, mounting holes.kicad_sch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]
2023-03-04 MCU swap, UCB components moved, crystal swap
    [Analog.kicad_sch, BOM-travaulta.csv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]
2023-03-10 clean up
    [travaulta rgb.kicad_pcb, travaulta rgb.kicad_sch, travaulta.kicad_pcb]
2023-03-13 changed reset button, new production files
    [BOM-travaulta.csv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]
2023-03-21 fresh production files
    [BOM-travaulta.csv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]
2023-04-01 rerouting matrix to fix error
    shifting around a bunch of switches, ending up with hopefully functional but not pretty routing
    [matrix.kicad_sch, travaulta.kicad_pcb]
2023-04-02 one pin matrix fix
    [Analog.kicad_sch, BOM-travaulta.csv, matrix.kicad_sch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]
2023-04-07 new production files
    [BOM-travaulta.csv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]
2023-04-13 edited preliminary firmware, small routing cleanups
    [travaulta plate niz-B_Cu.gbr, travaulta plate niz-B_Mask.gbr, travaulta plate niz-B_Paste.gbr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]
2023-04-15 tried to export dxf edge cut with all screw holes
    [travaulta plate niz-NPTH.drl, travaulta plate niz-PTH.drl]
2023-04-17 small schematic error fixed
    [matrix.kicad_sch, travaulta.kicad_pcb]
2023-05-02 revision started
    [Analog revision.kicad_sch, travaulta revision.kicad_pcb, travaulta revision.kicad_sch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]
2023-05-03 revision routing
    [travaulta revision.kicad_pcb]
2023-05-04 rerouting in progress
    [travaulta revision.kicad_pcb]
2023-05-04 tiny rerouting
    [travaulta revision.kicad_pcb]
2023-05-05 GND via revision
    [travaulta revision.kicad_pcb]
2023-05-06 revision routing further improved (edge problems addressed)
    [travaulta revision-B_Cu.gbr, travaulta revision-B_Mask.gbr, travaulta revision-B_Paste.gbr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]
2023-05-07 small tweaks
    [travaulta revision.kicad_pcb]
2023-05-11 reset button simplified
    [Analog.kicad_sch, matrix.kicad_sch, mounting holes.kicad_sch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]
2023-05-14 prototype files, fresh gerbers
    [Analog.kicad_sch, BOM-travaulta prototype.csv, BOM-travaulta.csv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]
2023-05-15 fresh gerbers
    deleted old plate gerbers, need new export
    [travaulta plate niz-B_Cu.gbr, travaulta plate niz-B_Mask.gbr, travaulta plate niz-B_Paste.gbr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]
2023-05-17 pcb clean up, fresh gerbers
    [travaulta plate niz.kicad_pcb, travaulta plate rgb.kicad_pcb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]
2023-06-07 cleaning up folder
    [Analog revision.kicad_sch, Analog.kicad_sch, BOM-travaulta.csv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]
2023-06-13 project cleanup
    [Analog revision.kicad_sch, travaulta plate niz.kicad_pcb, travaulta plate rgb.kicad_pcb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]
2023-08-01 silkscreen labelling changed for GB
    [travaulta.kicad_pcb]
2023-08-02 fresh set of production files
    [BOM-travaulta.csv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]
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2023-08-29 fresh gerbers, production files
    [BOM-travaulta.csv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]
2023-09-14 added WKL version (yet to be tested)
    [Analog.kicad_sch, matrix WKL.kicad_sch, mounting holes.kicad_sch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]
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2023-11-09 plate files updated, new production files
    [travaulta plate topre-B_Cu.dxf, travaulta plate topre-B_Mask.dxf, travaulta plate topre-Edge_Cuts.dxf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]
2023-11-17 added rgb breakout to HHKB&WKL
    [Analog.kicad_sch, matrix.kicad_sch, mounting holes.kicad_sch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]
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2023-12-16 renamed rgb to hhkb for clarity
    [Analog.kicad_sch, matrix.kicad_sch, mounting holes.kicad_sch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]
2024-01-19 fresh gerbers WKL, backup
    [travaulta WKL-B_Cu.gbr, travaulta WKL-B_Mask.gbr, travaulta WKL-B_Paste.gbr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]
2024-01-31 changed rgb pin on HHKB&WKL for better compatibility
    [Analog.kicad_sch, matrix.kicad_sch, mounting holes.kicad_sch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]
2024-02-09 fresh gerbers for HHKB WKL
    [travaulta HHKB-B_Cu.gbr, travaulta HHKB-B_Mask.gbr, travaulta HHKB-B_Paste.gbr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]
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2024-08-07 added fresh plate files
    [travaulta_hhkb_non threaded.dxf, travaulta_hhkb_threaded.dxf]
2025-03-01 added WKL & numpad
    [Analog.kicad_sch, BOM-numbpad.csv, BOM-travaulta HHKB.csv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]
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2025-09-22 added naevies plate for hhkb
    [travaulta plate naevies fr4-B_Cu.gbr, travaulta plate naevies fr4-B_Mask.gbr, travaulta plate naevies fr4-B_Paste.gbr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]
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

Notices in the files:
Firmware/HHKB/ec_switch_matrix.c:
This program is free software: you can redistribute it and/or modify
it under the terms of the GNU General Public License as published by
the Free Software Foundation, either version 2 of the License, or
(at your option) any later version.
